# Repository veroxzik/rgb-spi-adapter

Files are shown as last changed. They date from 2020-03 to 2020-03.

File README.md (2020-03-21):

# rgb-spi-adapter
 Simple breakout board for the TLC59711 for use with rhythm game controllers.

## Current Release

v1.1 swaps the RGB headers around for compatibility with Yuancon controllers.

## Explanation
Designed for common anode RGBs. Individually wired works just fine too.

- Connectors are JST-XH 4 pin.
- Capacitors are 1uF 0805.
- Resistor is 0805, value per TLC59711 datasheet for your desired current.
- Solder jumper only if you're using 3.3V voltage across the board (LED and logic). Otherwise leave it open for 5V.

Use Adafruit TLC59711 library (get from Arduino library manager). It's plug and play!

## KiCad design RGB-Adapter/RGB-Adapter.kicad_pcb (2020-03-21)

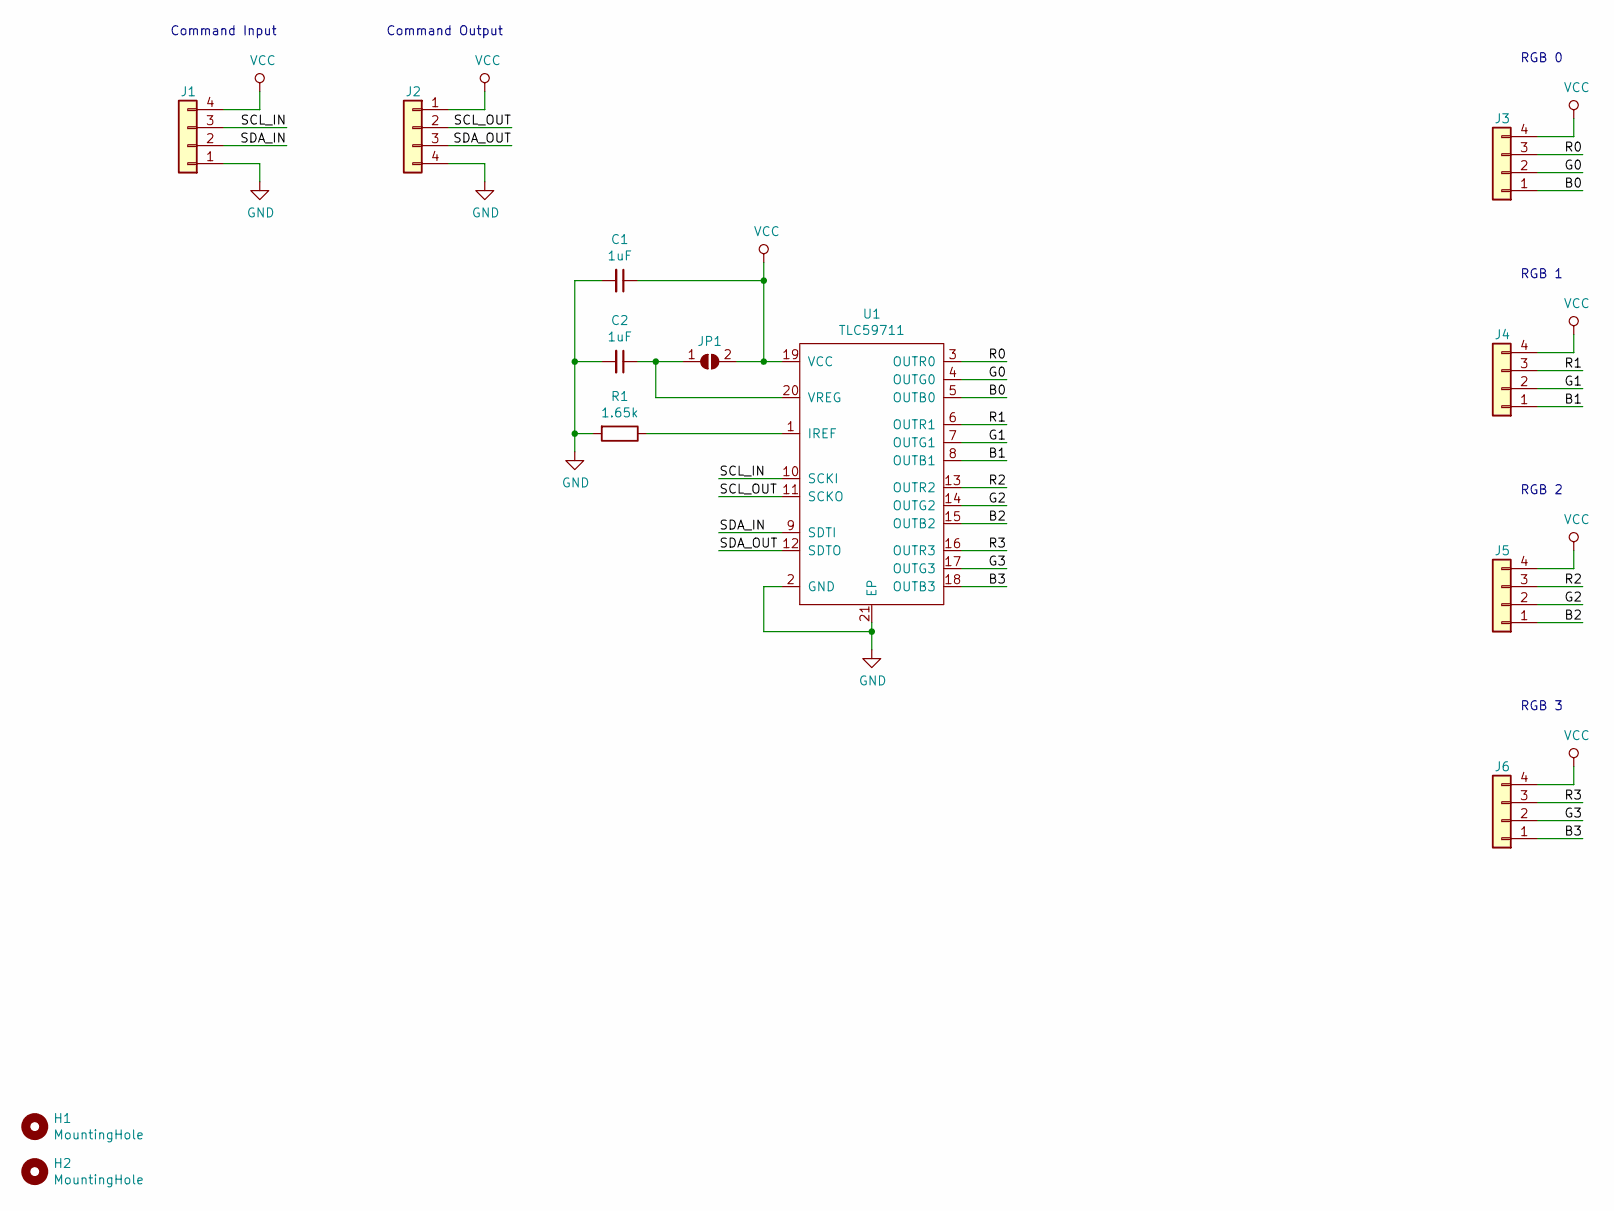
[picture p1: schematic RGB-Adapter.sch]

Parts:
C1, C2: 1uF; C_0603_1608Metric_Pad1.05x0.95mm_HandSolder
H1, H2: MountingHole; MountingHole_3.2mm_M3_DIN965
J1, J2, J3, J4, J5, J6: Conn_01x04; JST_XH_B4B-XH-A_1x04_P2.50mm_Vertical
JP1: SolderJumper_2_Open; SolderJumper-2_P1.3mm_Open_RoundedPad1.0x1.5mm
R1: 1.65k; R_0603_1608Metric_Pad1.05x0.95mm_HandSolder
U1: TLC59711; HTSSOP-20-1EP_4.4x6.5mm_P0.65mm_EP3.4x6.5mm_Mask2.75x3.43mm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

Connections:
/B0: J3.1, U1.5 (OUTB0)
/B1: J4.1, U1.8 (OUTB1)
/B2: J5.1, U1.15 (OUTB2)
/B3: J6.1, U1.18 (OUTB3)
/G0: J3.2, U1.4 (OUTG0)
/G1: J4.2, U1.7 (OUTG1)
/G2: J5.2, U1.14 (OUTG2)
/G3: J6.2, U1.17 (OUTG3)
/R0: J3.3, U1.3 (OUTR0)
/R1: J4.3, U1.6 (OUTR1)
/R2: J5.3, U1.13 (OUTR2)
/R3: J6.3, U1.16 (OUTR3)
/SCL_IN: J1.3, U1.10 (SCKI)
/SCL_OUT: J2.2, U1.11 (SCKO)
/SDA_IN: J1.2, U1.9 (SDTI)
/SDA_OUT: J2.3, U1.12 (SDTO)
GND: C1.2, C2.2, J1.1, J2.4, R1.2, U1.2 (GND), U1.21 (EP)
unnamed: C2.1, JP1.1 (A), U1.20 (VREG)
unnamed: R1.1, U1.1 (IREF)
VCC: C1.1, J1.4, J2.1, J3.4, J4.4, J5.4, J6.4, JP1.2 (B), U1.19 (VCC)

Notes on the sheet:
Command Input
RGB 0
Command Output
RGB 1
RGB 2
RGB 3

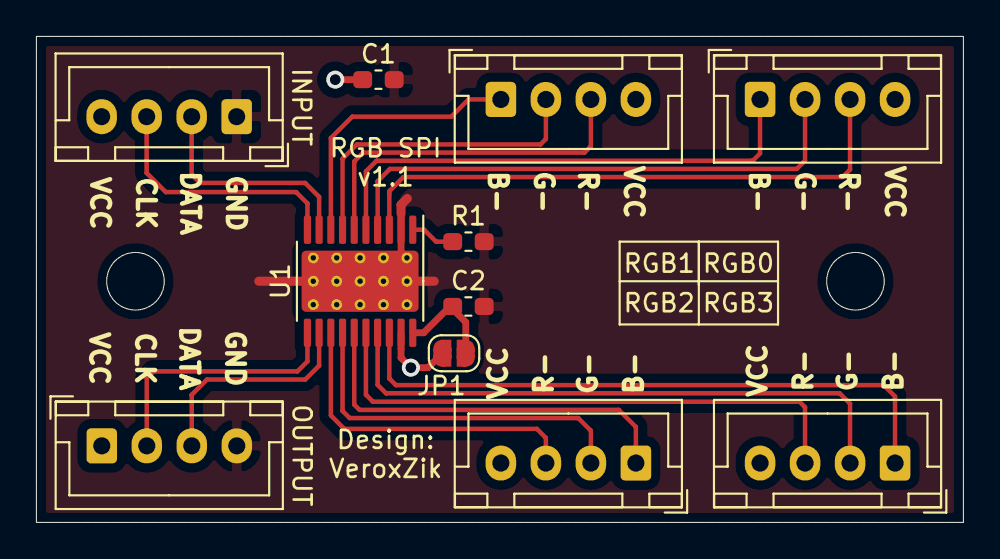
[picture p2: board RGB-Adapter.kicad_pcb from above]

Board: 2 copper layers, 51.5 x 27.0 mm, 13 parts (0 on the bottom side), 20 nets.
